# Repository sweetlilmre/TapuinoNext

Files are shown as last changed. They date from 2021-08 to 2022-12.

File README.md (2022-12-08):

# TapuinoNext


## Intro

Welcome to the TapuinoNext alpha.  

Most of the code has been written and tested to a fair extent, but there are bound to be loads of bugs.
Please report bugs as issues against the repo. If you have fixes, please submit these as a pull request.
I could really use some help with documentation in markdown format if you would like to contribute in that way.

## Using the TapuinoNext

Instructions on how to navigate the UI and detail on the TapuinoNext functionality can be found on this page: [TapuinoNext UI](docs/ui/TapuinoNext-UI.md). This is still very much a work in progress.

## Hardware

- "instructions" to build a stripboard prototype are available at [Prototype Build](docs/PrototypeBuild.md)
- schematics and board designs for reference implementations are available in the [Eagle](docs/Eagle) folder.
- the mini board has been produced and tested successfully!
- **NB: the micro board has not**

The BOM for the TapuinoNext is:
- ESP32 Devkit equivalent: e.g. https://www.banggood.com/ESP32-WiFi-+-bluetooth-Development-Board-Ultra-Low-Power-Consumption-Dual-Core-ESP-32-ESP-32S-Similar-ESP8266-Geekcreit-for-Arduino-products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

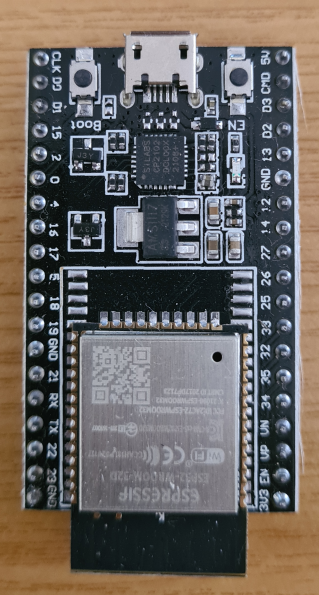
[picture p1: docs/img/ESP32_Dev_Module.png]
ESP32 Dev Module SD Card Adapter


- resistors:
  - (voltage divider)
    - 1k5
    - 3k3
  - 100 Ohm (Recording LED current limiter)
- Rotary encoder KY-040: e.g. https://www.banggood.com/5Pcs-5V-KY-040-Rotary-Encoder-Module-AVR-PIC-p-951151.html

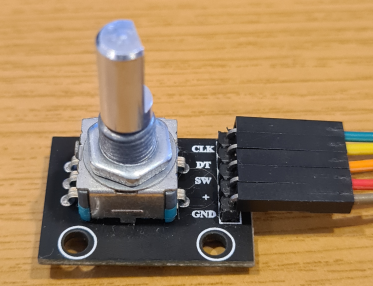
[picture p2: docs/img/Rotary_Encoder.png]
KY-040 Rotary Encoder


- LCD screen: SSD1306 OLED or HD44780 via I2C backpack
- SD Card breakout board / socket, no level shifter! Ones without resistors seem to work better. I used something like this: https://www.mischianti.org/2019/12/15/how-to-use-sd-card-with-esp8266-and-arduino/
This is the one I built:

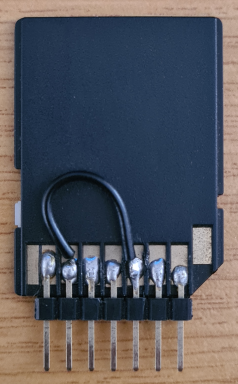
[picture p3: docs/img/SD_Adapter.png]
SD Card Adapter


- Bi-directional level shifter: e.g. https://www.banggood.com/10Pcs-Logic-Level-Converter-Bi-Directional-IIC-4-Way-Level-Conversion-Module-p-1033750.html
  
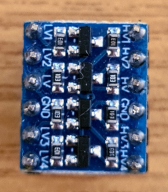
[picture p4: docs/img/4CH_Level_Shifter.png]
4 Channel Level Shifter


- C64 Datasette connector (use one off of a dead datasette or find one of these: https://www.thefuturewas8bit.com/cassette-port-connector-vic20-64-64c-128-128d-pet.html)

Wire this all up according to the schematic and flash the firmware.

## Firmware

If you have already flashed a recent firmware, then firmware releases are available at: https://github.com/sweetlilmre/TapuinoNext/releases

As newer firmware can self update, all you need to do is drop the *update.bin* file onto the root of the SD Card and select the firmware update option from the options menu.

For a first time build:

There is now an alternative to building the code and flashing.
- Download the latest `update.factory.bin` from the [TapuinoNext Releases Page ](https://github.com/sweetlilmre/TapuinoNext/releases)
- Using Google Chrome, go to the [Adafruit ESP Tool](https://adafruit.github.io/Adafruit_WebSerial_ESPTool/) page.
- Connect your ESP32 to your machine and make sure the drivers are installed
- Click "Connect" on the Adafruit page and select the COM port of your ESP32
- If the connect succeeds, you should see several `Choose a file...` buttons
- Click the first one, navigate to and select the `update.factory.bin` file you downloaded
- Click `Program`
- A progress bar will appear, once this is complete you should be good to go

Probably the easiest way to handle this at the moment is to:
- install VS Code
- install Platformio on top of that
- install the Espressif 32 platform or start a new project and choose "Espressif ESP32 Dev Module" as the board, with "Arduino" as the framework
- clone the TapuinoNext repository
- you will need to create a ***config-user.h*** file in the include directory. This is currently used to specify which of the 2 supported displays you have and what the correct I2C address for the display is. A sample ***config-user.h.example*** has beem provided
- point VS code to the directory you cloned the repo into and upload to the board (I'm assuming that you know how to do all of this)

## TODO / Roadmap

See [TODO](TODO.md)

## Attribution

See [Attribution](docs/Attribution.md)

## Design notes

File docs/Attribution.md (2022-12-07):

# Attibution for documentation and hardware designs:

## Fritzing
### TapuinoNext layout:

- Original design: Attila Gabriel  
- Fixes and edits by sweetlilmre

### Components:

ESP32-38PinWide-Component.fzpz:  
- https://forum.fritzing.org/t/fritzing-part-of-an-esp32/5355/4
  - https://forum.fritzing.org/uploads/default/original/2X/8/8d99adbb2e8f966178bdb46f5cffa7bd72ce2c2a.fzpz

KY-040_AZ_Rotary_encoder_v0.fzpz:  
- https://forum.fritzing.org/t/ky-040-rotary-encoder-breakout-board-part/11073
  - https://forum.fritzing.org/uploads/short-url/bN5n4wTJwT4cgNHyY3Omdc8aznC.fzpz

SD_Card_Module.fzp:  
- https://github.com/robertoostenveld/fritzing/blob/master/SD%20Card%20Module.fzpz
  - https://github.com/robertoostenveld/fritzing/raw/master/SD%20Card%20Module.fzpz

## Eagle parts
2 Pin Header part  
For some inexplicable reason the built in Eagle libraries do not have a 2 pin male header (starts at 3 pin). This part is a rework of the 3 pin part.  
<br>
ESP32 Devkit part  
Nothing on the internet that I could find had either the correct pin out or size for the dev kit board. I have created a part heavily inspired by the following:
- https://hackaday.io/project/46280-muffsy-stereo-relay-input-selector/log/87314-esp32s-devkit-eagle-library
  - https://cdn.hackaday.io/files/462801980043520/ESP32-DEVKITC.lbr
## Others:
PNG Images, stripboard design, schematics, board and libraries
- sweetlilmre

## Factory bin image generation script:
https://raw.githubusercontent.com/letscontrolit/ESPEasy/3678488f6a67ac9b899fab3d0ccd176c4437b1b4/tools/pio/post_esp32.py

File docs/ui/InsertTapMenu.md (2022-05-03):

# TapuinoNext UI

## Insert Tap

Once you have selected this menu option you will be taken to the file browser. Navigate through the files to select a TAP file you wish to load and then use the **Button** action to select that file.

Directories can be selected in the same manner, use the previous directory ".." to go up one level.

TAP files with names longer than the LCD display width will scroll after a short pause. The scroll rate can be changed in the [Options Menu](/docs/ui/OptionsMenu.md).

Once you have selected a TAP file, the file will be verified and on success you will be taken to the [Play Menu](PlayMenu.md).

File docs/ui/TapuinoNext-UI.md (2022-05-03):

# TapuinoNext UI

## Navigation

The rotary encoder is used to navigate through the various menus, options and functions of the firmware.

| Encoder action | Description | UI Result |
| --- | --- | --- |
| Left | Turn encoder anti-clockwise | Previous menu / item |
| Right | Turn encoder clockwise | Next menu / item |
| Button | Press the encoder button | Select |
| ButtonHold | Press and hold the encoder button | Back / cancel |

The **Button** and **ButtonHold** actions have context specific functionality that will be described in the corresponding help sections.

### Menu Navigation

- Use the encoder to scroll through the menus at the current level.
- Use **Button** to select a sub-menu / action
- Use **ButtonHold** to return to the previous menu

## Main Menu

Once the TapuinoNext has booted successfully (displayed the startup screen with version number and initialised) the Main Menu will display, defaulting to the first option: Insert Tap

Scroll through these options using the encoder and then use the **Button** to select one. The 3 main menu options are:

- [Insert Tap](InsertTapMenu.md)
- [Record Tap](RecordTapMenu.md)
- [Options](OptionsMenu.md)

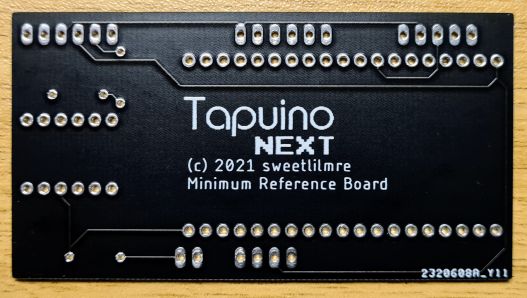
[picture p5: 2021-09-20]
docs/img/TapuinoNext-Mini.jpg

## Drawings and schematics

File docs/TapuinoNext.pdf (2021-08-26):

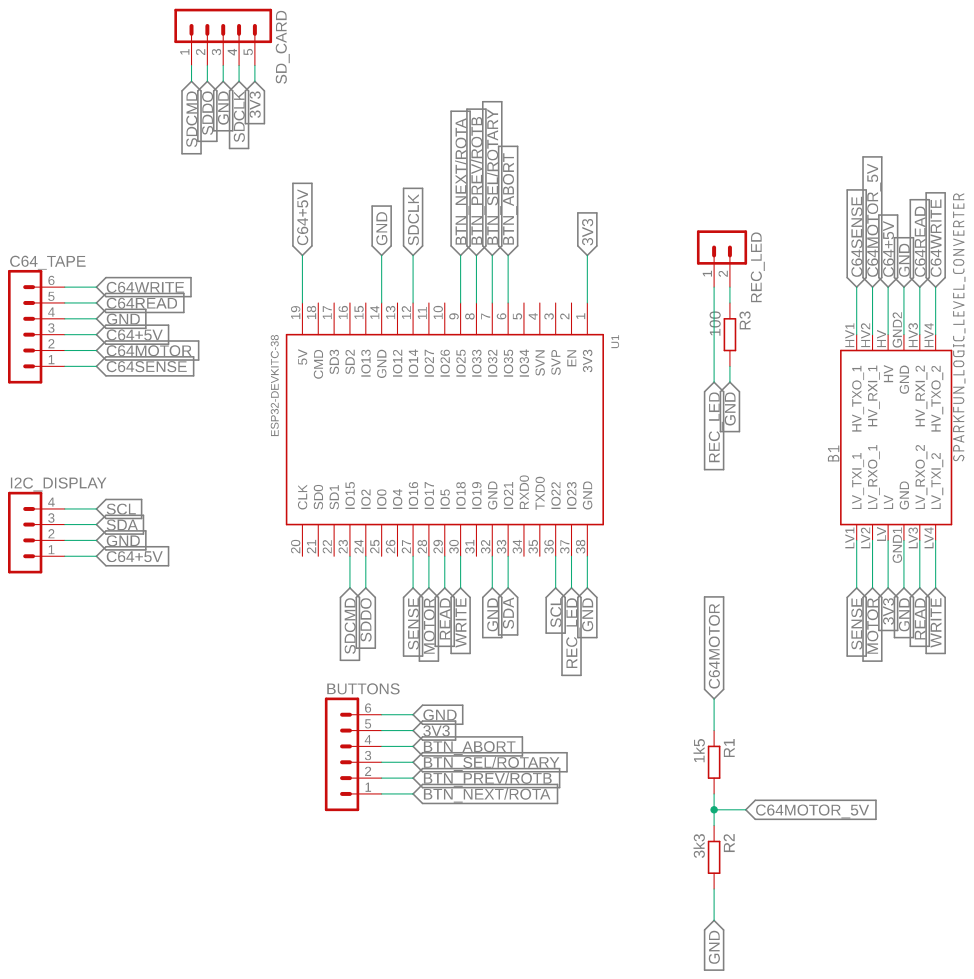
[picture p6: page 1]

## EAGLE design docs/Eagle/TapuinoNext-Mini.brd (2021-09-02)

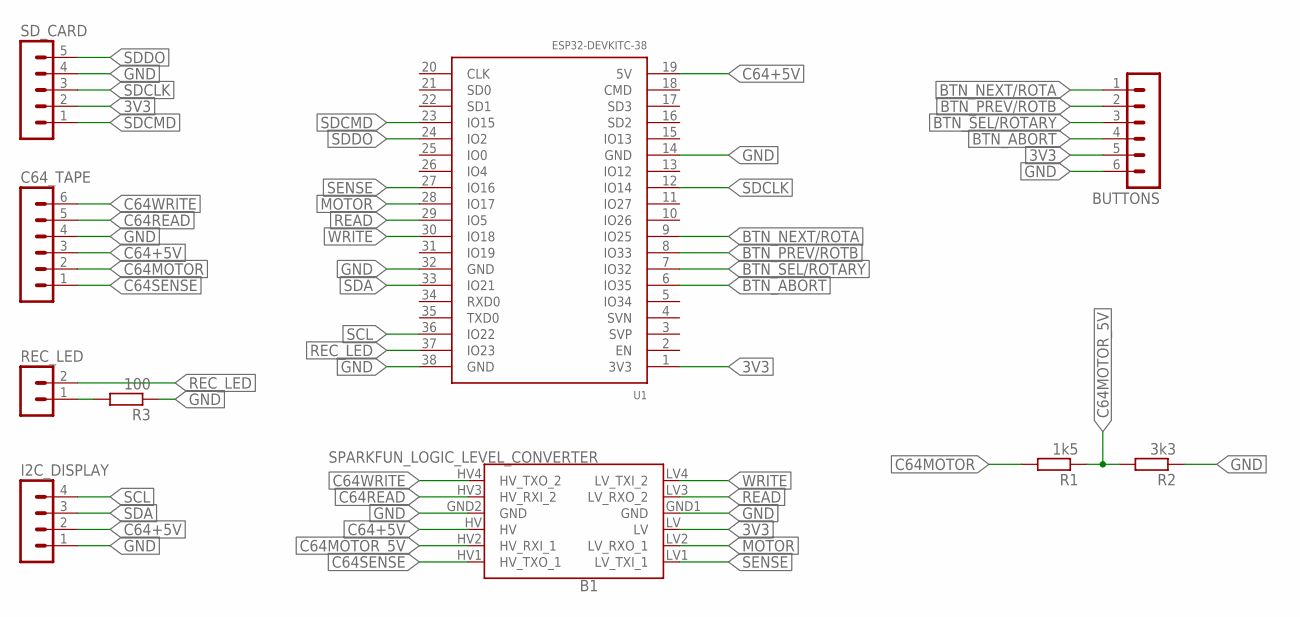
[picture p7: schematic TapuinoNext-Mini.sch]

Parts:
B1: SPARKFUN_LOGIC_LEVEL_CONVERTER
BUTTONS: MA06-1
C64_TAPE: MA06-1
I2C_DISPLAY: MA04-1
R1: 1k5; 0207/10
R2: 3k3; 0207/10
R3: 100; 0207/10
REC_LED: MA02-1
SD_CARD: MA05-1
U1: ESP32-DEVKITC-38

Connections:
3V3: B1.LV, BUTTONS.5, SD_CARD.2, U1.1 (3V3)
BTN_ABORT: BUTTONS.4, U1.6 (IO35)
BTN_NEXT/ROTA: BUTTONS.1, U1.9 (IO25)
BTN_PREV/ROTB: BUTTONS.2, U1.8 (IO33)
BTN_SEL/ROTARY: BUTTONS.3, U1.7 (IO32)
C64+5V: B1.HV, C64_TAPE.3, I2C_DISPLAY.2, U1.19 (5V)
C64MOTOR: C64_TAPE.2, R1.2
C64MOTOR_5V: B1.HV2 (HV_RXI_1), R1.1, R2.2
C64READ: B1.HV3 (HV_RXI_2), C64_TAPE.5
C64SENSE: B1.HV1 (HV_TXO_1), C64_TAPE.1
C64WRITE: B1.HV4 (HV_TXO_2), C64_TAPE.6
GND: B1.GND1 (GND), B1.GND2 (GND), BUTTONS.6, C64_TAPE.4, I2C_DISPLAY.1, R2.1, R3.1, SD_CARD.4, U1.14 (GND), U1.32 (GND), U1.38 (GND)
MOTOR: B1.LV2 (LV_RXO_1), U1.28 (IO17)
unnamed: R3.2, REC_LED.1
READ: B1.LV3 (LV_RXO_2), U1.29 (IO5)
REC_LED: REC_LED.2, U1.37 (IO23)
SCL: I2C_DISPLAY.4, U1.36 (IO22)
SDA: I2C_DISPLAY.3, U1.33 (IO21)
SDCLK: SD_CARD.3, U1.12 (IO14)
SDCMD: SD_CARD.1, U1.23 (IO15)
SDDO: SD_CARD.5, U1.24 (IO2)
SENSE: B1.LV1 (LV_TXI_1), U1.27 (IO16)
WRITE: B1.LV4 (LV_TXI_2), U1.30 (IO18)

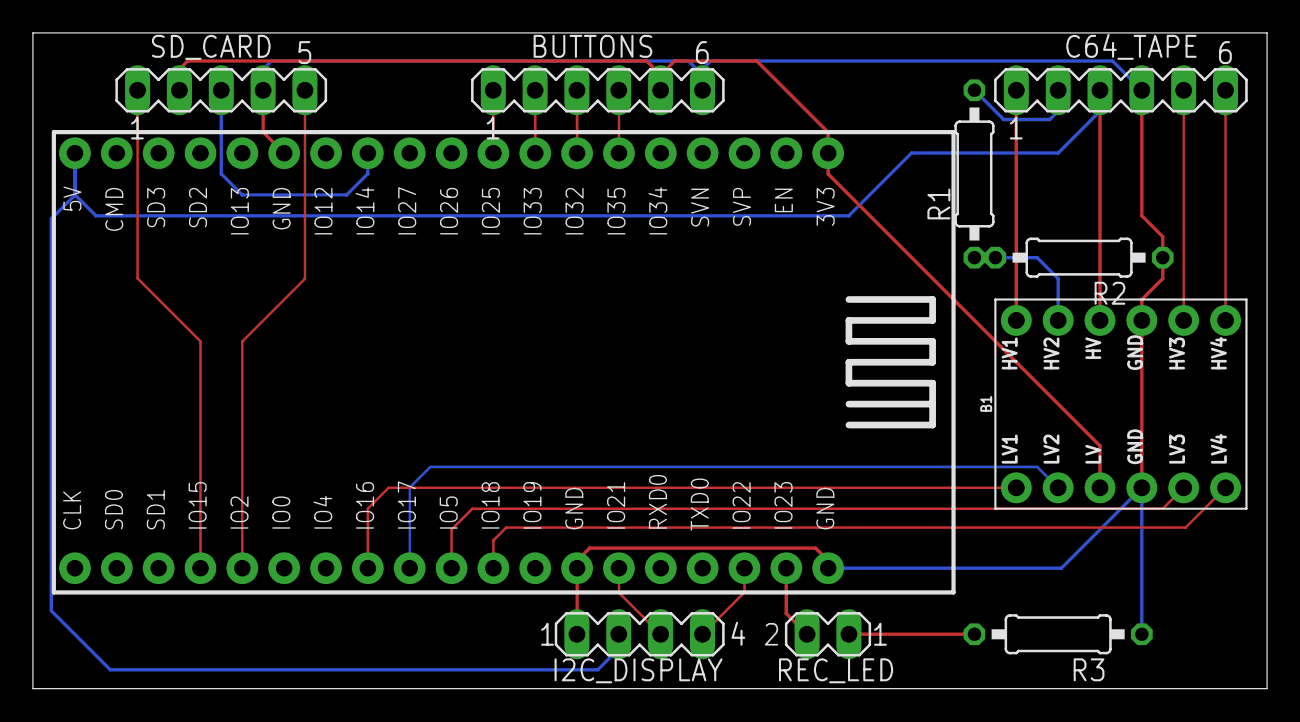
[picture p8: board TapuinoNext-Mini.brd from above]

Board: 2 copper layers, 74.9 x 39.8 mm, 10 parts (0 on the bottom side), 23 nets.

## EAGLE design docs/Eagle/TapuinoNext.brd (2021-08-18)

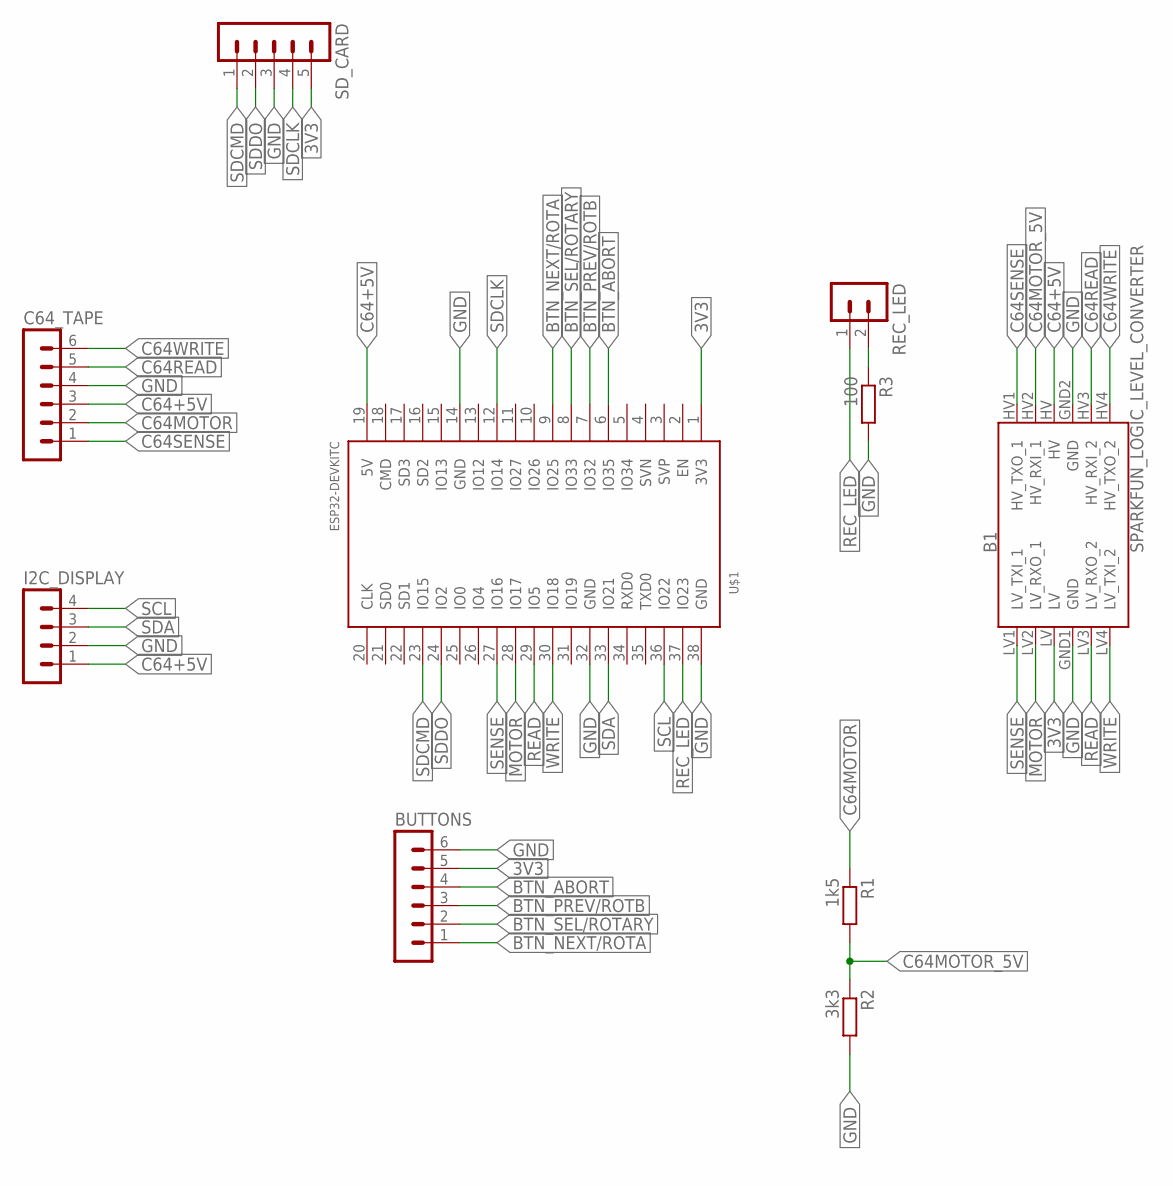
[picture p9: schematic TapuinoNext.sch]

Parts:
B1: SPARKFUN_LOGIC_LEVEL_CONVERTER
BUTTONS: MA06-1
C64_TAPE: MA06-1
I2C_DISPLAY: MA04-1
R1: 1k5; 0204/7
R2: 3k3; 0204/7
R3: 100; 0204/7
REC_LED: MA02-1
SD_CARD: MA05-1
U$1: ESP32DEVKITC; ESP32-DEVKITC

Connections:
3V3: B1.LV, BUTTONS.5, SD_CARD.5, U$1.1 (3V3)
BTN_ABORT: BUTTONS.4, U$1.6 (IO35)
BTN_NEXT/ROTA: BUTTONS.1, U$1.9 (IO25)
BTN_PREV/ROTB: BUTTONS.3, U$1.7 (IO32)
BTN_SEL/ROTARY: BUTTONS.2, U$1.8 (IO33)
C64+5V: B1.HV, C64_TAPE.3, I2C_DISPLAY.1, U$1.19 (5V)
C64MOTOR: C64_TAPE.2, R1.1
C64MOTOR_5V: B1.HV2 (HV_RXI_1), R1.2, R2.1
C64READ: B1.HV3 (HV_RXI_2), C64_TAPE.5
C64SENSE: B1.HV1 (HV_TXO_1), C64_TAPE.1
C64WRITE: B1.HV4 (HV_TXO_2), C64_TAPE.6
GND: B1.GND1 (GND), B1.GND2 (GND), BUTTONS.6, C64_TAPE.4, I2C_DISPLAY.2, R2.2, R3.2, SD_CARD.3, U$1.14 (GND), U$1.32 (GND), U$1.38 (GND)
MOTOR: B1.LV2 (LV_RXO_1), U$1.28 (IO17)
unnamed: R3.1, REC_LED.2
READ: B1.LV3 (LV_RXO_2), U$1.29 (IO5)
REC_LED: REC_LED.1, U$1.37 (IO23)
SCL: I2C_DISPLAY.4, U$1.36 (IO22)
SDA: I2C_DISPLAY.3, U$1.33 (IO21)
SDCLK: SD_CARD.4, U$1.12 (IO14)
SDCMD: SD_CARD.1, U$1.23 (IO15)
SDDO: SD_CARD.2, U$1.24 (IO2)
SENSE: B1.LV1 (LV_TXI_1), U$1.27 (IO16)
WRITE: B1.LV4 (LV_TXI_2), U$1.30 (IO18)

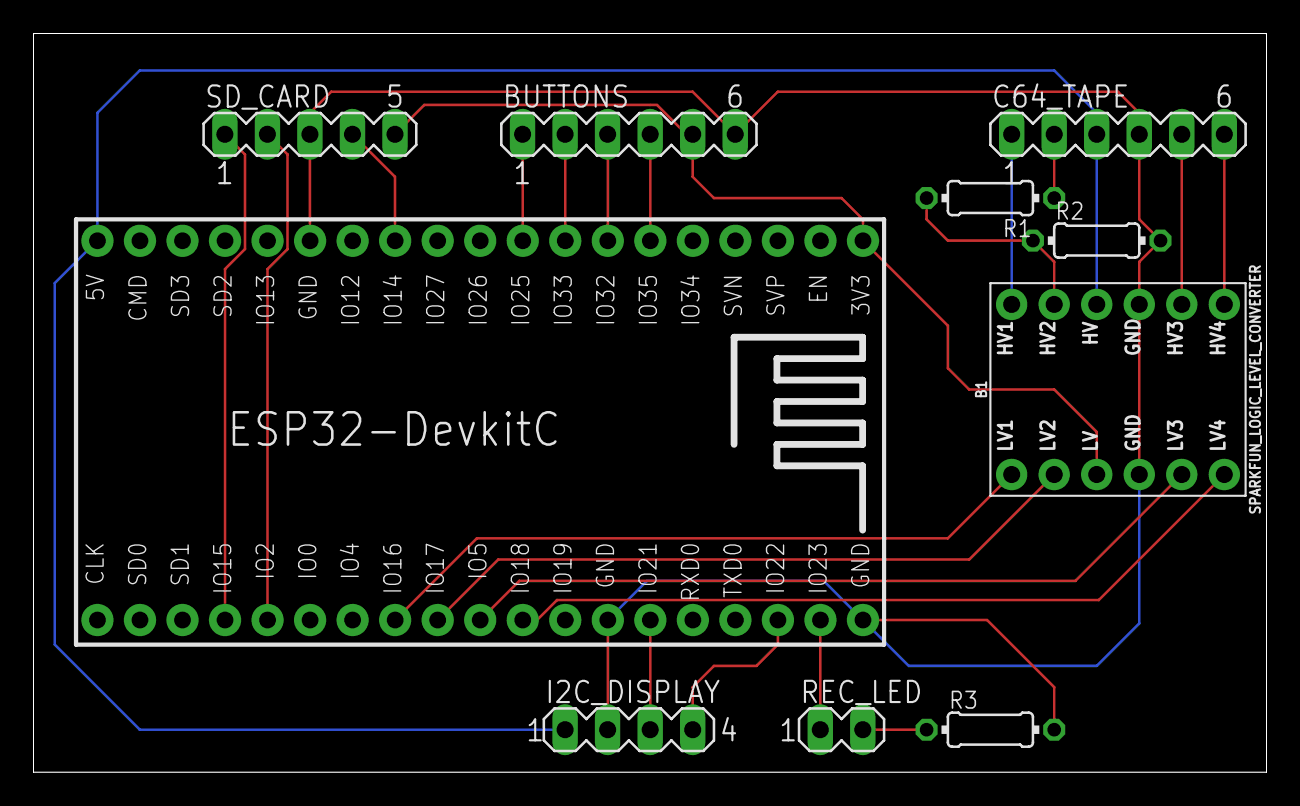
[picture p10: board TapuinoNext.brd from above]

Board: 2 copper layers, 73.6 x 44.1 mm, 10 parts (0 on the bottom side), 23 nets.

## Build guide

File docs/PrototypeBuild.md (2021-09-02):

# The first working prototype
This was built on stripboard. The design is in the LochMaster folder (you can download the LochMaster demo for free IIRC).

## Stripboard Legend
Please pay careful attention to the legend, specifically the cut track marks.  
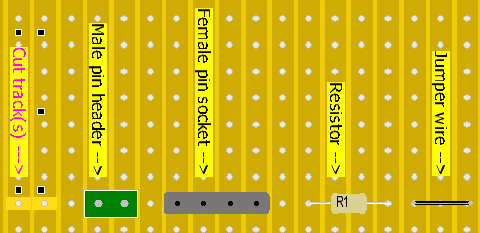
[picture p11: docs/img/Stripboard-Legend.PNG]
Stripboard Legend


## Stripboard Top View
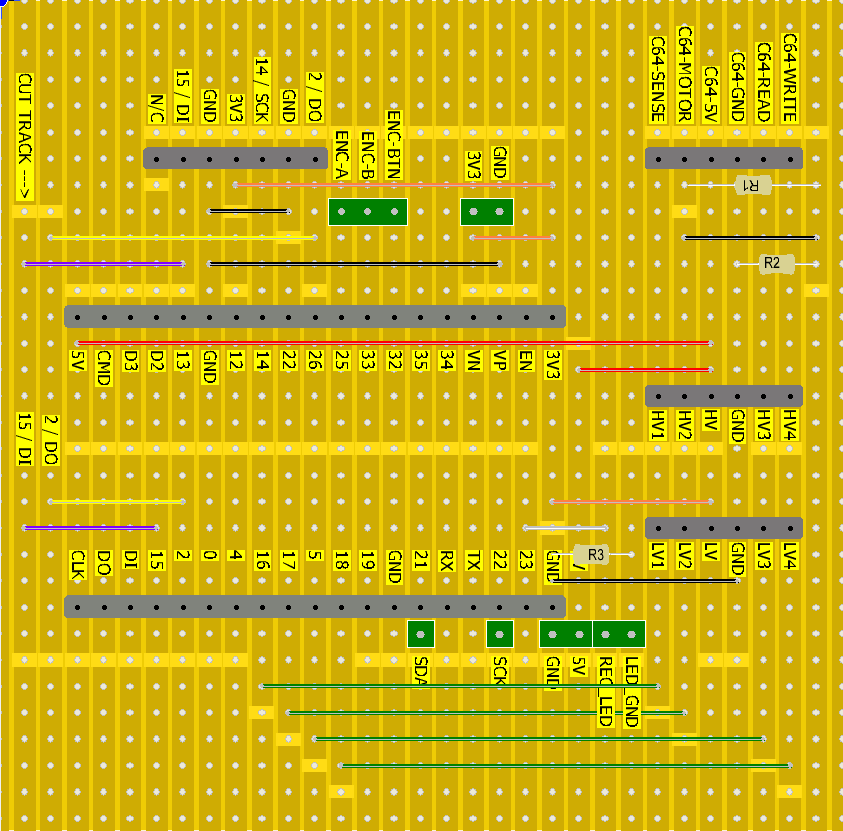
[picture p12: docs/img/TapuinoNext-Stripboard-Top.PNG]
Stripboard Top View


## Stripboard xray view
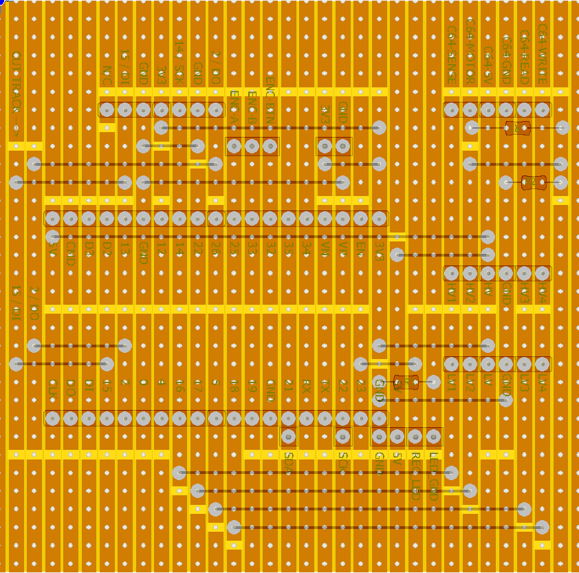
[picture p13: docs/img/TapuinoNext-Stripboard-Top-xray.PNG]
Stripboard xray View


## Stripboard used area view
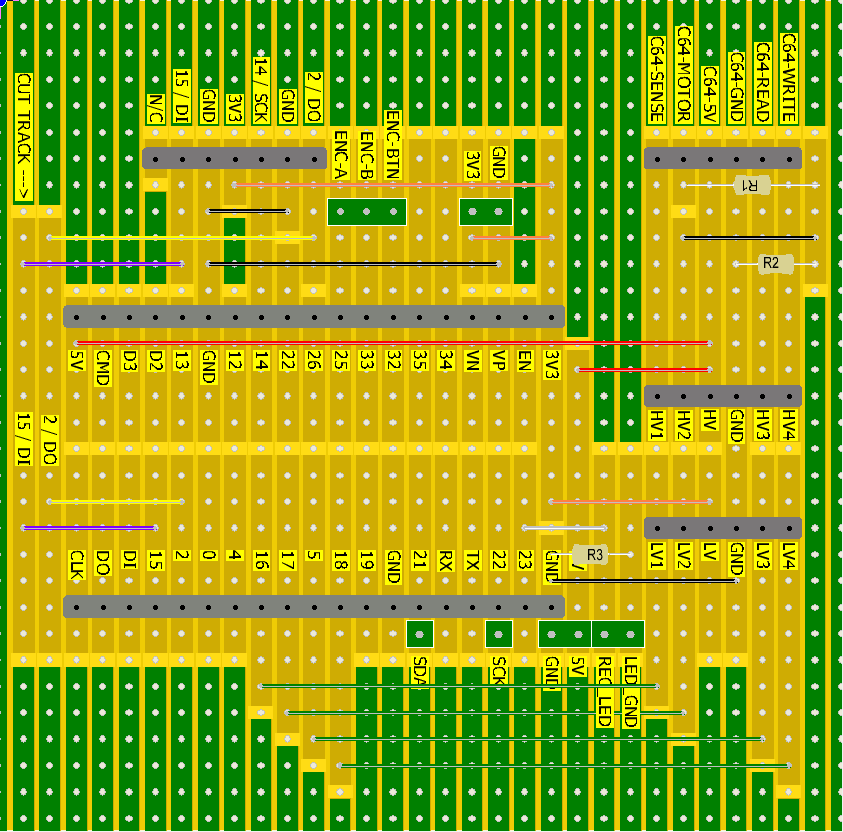
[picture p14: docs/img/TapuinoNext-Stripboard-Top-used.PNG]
Stripboard Used Area View


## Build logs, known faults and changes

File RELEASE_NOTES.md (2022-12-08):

*****************************************
** TapuinoNext Release Notes           **
** sweetlilmre <sweetlilmre@gmail.com> **
*****************************************

## v0.0.3-alpha+267 - 08 December 2022

### Feature
  - Added `update.factory.bin` to the build and release artifacts
  - Updated documentation to show how to flash the firmware from a browser, using `update.factory.bin`
  - Internal changes to support the above

### Fix
  - Fixed printing of the TapuinoNext version to the serial port 

## v0.0.3-alpha+240 - 22 June 2022

### Feature
  - Added file filtering change to exclude files starting with . (remove Mac specific folders) (predecker)
  - Added TODO.md to keep some kind of roadmap going

### Fix
  - Previous directory fix (predecker)
  - Changed start recording message to be clearer

### Internal
  - Changed changelog format for automatic release note generation
  - Added 'v' to version, should have been there from the begining
    - fixed auto_version.py to support this
  - Moved large buffer handling to FlipBuffer
    - Cleaned up implementation in TapLoader and TapRecorder
  - Added raw TapeCart implementation code

## v0.0.2-alpha+237 - 04 June 2022
  - Fixed various compatibility issues with framework-arduinoespressif32 > 2.0.1
    - the platform is pinned to version 4.0.1 (and hence framework 2.0.1) waiting for timer fixes to get into the next framework release and platform update (4.0.5 and 2.0.4?)
    - timer functionality was changed from a re-triggered one-shot to a repeat timer (retriggered one-shot does not work in the context of the move to IDF4.4 from framework 2.0.2)
    - input initialisation in the constructor of ESP32InputHandler.cpp also broke (shouldn't have done this in the first place)

  - Other minor improvments
    - changed the text for the firmware update menu to make it less confusing
    - added the spinner UI into the update progress display
    - changed the name of the firmware release to "update.bin" for ease of use

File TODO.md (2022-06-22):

**TODO / Roadmap**

- Implement ini file for LCD selection, write default if it does not exist
  - Defaults will be
    - `#define I2C_DISP_ADDR 0x27`
    - `#define I2C_DISP_TYPE I2C_DISP_TYPE_HD44780`
- Finish TapeCart implementation
  - Run basic test with a buffer and built in PRG to test timing and handshake with C64 loader
    - Changed approach to use a file, still to test, requires changes below
    - ~~Implement basic loader pre-code check for $0801 load address PRGs~~
    - ~~Might need to change the loader to wait for the sense line signal (currently commented out), but would be useful to allow setup time for files / buffers~~
      - Looks like the wait on SENSE will take care of this
  - ~~Move buffer handling to a separate class (save on heap space, share buffer and have single allocation)~~
  - Add PRG as allowable extension to LoadSelector
    - Differentiate behaviour depending on TAP / PRG load
- C16 TAP (1/2 wave) playback
  - Fix cycle counting
  - Implement 1/2 wave recording
- Implement other machine type timings (PET etc) and check values against Vice
- Add file / dir filter to remove hidden directories (MacOS / Win / etc?)
  - Waiting on PR from contributor

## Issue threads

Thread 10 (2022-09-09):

Question regarding sense signal & record LED

Pentasis, 2022-09-09:
Hi, sorry for asking this here.
I am currently building (well, designing for now) a tapuino into an old 1530 case. I want to keep it as original as possible, so I put the display and the sd-card into the tape-lid and reuse the original buttons (which is a bit of a challenge).

I also want the counter to actually work (just because), so I intend to put a small motor in there. I'm still in the design-stage so don't have the actual parts yet. I want it to turn only when reading/writing. Is the sense-signal suitable for that? Is it continuously on while reading/writing? Also, is it 5V?

Also, I assume the record_LED only works when recording (writing) not reading, right? As a feature request, could a read_LED be implemented? (In the end I will probably use a multi-colour-led as a replacement for the original one and have it switch colours depending on power/read/write)

sweetlilmre, 2022-09-12:
Hi there,

SENSE is activated on the datasette by pressing PLAY (or record and play). IIRC it will be on for the duration, although there are cases where  SENSE will be active but the motor has stopped (game has finished loading). As I have the correct formula for calculating the counter, I would suggest replacing the analogue counter with a digital one and we could look at some digital interface to communicate the value (I2C perhaps?). A small oled screen or very small I2C 3-digit 7 segment display could be awesome for this.

As for LEDs, there are plenty of pins available so I could add read and/or write LEDS, something I had meant to do.

How are you building the TapuinoNext? On breadboard or using the reference PCB? I might need to change some pin assignments if I'm going to add further LEDs or a counter interface to the code and will then need to update the schematic if you are using the PCB.

sweetlilmre, 2022-12-17:
Closing this issue as no response from OP.

Closed 2022-12-17.

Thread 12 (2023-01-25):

Tapuino + touch GUI

dejwk, 2023-01-25:
Hi Peter,

I see that you are porting Tapuino to ESP32. It's very cool, since ESP32 is so much more capable!

Anyway - my name is Dawid, and I wrote a GUI library for the ESP32. As a proof-of-concept, I wrote a GUI app for Tapuino. I made a short YouTube demo video, here:

https://www.youtube.com/watch?v=Aub32NOzwNY

In addition to the GUI part, it's probably worth noting that it supports loading directly from ZIP files, and it can handle SD cards with thousands of TAPs.

If you were interested, I'd be happy to contribute that app to be part of your project.

The GUI lib is still somewhat experimental (e.g. no documentation); with that caveat, you can find it here: https://github.com/dejwk/roo_windows. I didn't upload the app itself to Github just yet.

The TFT I used isn't great (it has a resistive touch, and it needs a stylus), but it's cheap and it has a built-in SD card reader. Hence, for my prototype build, I only needed two active components (ESP32 + display), and just a few passive elements. There are better TFTs, though. I have good experience with Waveshare ILI9486-based; I also ordered something with capacitive touch to experiment with.

sweetlilmre, 2023-02-21:
Hi Dawid,
I was sure I had responded to you, but must have forgot to send the response.

This looks like a really nice GUI and I'd be keen to support something like this.
What I do need to do first is some abstraction work on the current UI handling so that multiple UIs could be integrated depending on hardware choice. I'd be interested to see how you wove your UI into the current project.

Apologies for getting back to you so late.

dejwk, 2023-03-01:
Thanks Peter!

I dumped the PoC here if you'd like to take a look: https://github.com/dejwk/tapuino2

(It depends on a number of libs from https://github.com/dejwk; I didn't yet do anything to make it easy to build, so if you'd like to build it, you'll need to manually fetch roo_time, roo_scheduler, roo_display, roo_windows, roo_material_icons, and roo_dashboard - by cloning them into the lib/ subdirectory. It also needs  unzipLIB to handle ZIP files.)

It is a proof-of-concept; it doesn't support seek, updates, and writes - but all possible to add. I also intended to implement a search-as-you-type interface; the index is prepared for that but the UI isn't implemented yet.

The most recent implementation uses a MakerFabs display (based on ili9488), which I am very pleased with - it has very good resolution (480x320), an excellent capacitive touch panel, and ESP32 and SD card reader on board - so really the only bits needed to make a functional Tapuino out of that single component are a few passive elements (voltage dividers and a capacitor on the power line). That said, the underlying UI library supports a number of TFT display drivers so there's some flexibility built-in.

Re: how to refactor the project so that it can work with different UX interfaces: I think the way to go is to make the core event-driven. That is, the 'main loop' needs to be outside of the core, and controlled by the specific UI implementation. Then, you can have completely different UX on top of the same core. (By core, I mean the code that handles the filesystem, TAP playback, etc.)

This is how my PoC is currently implemented, so you can see what I mean in the code. Basically, the UX *is* the app, and it calls to the core when needed, e.g. when something is pressed, as well as periodically during playback (to replenish the read buffer).

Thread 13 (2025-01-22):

Unfortunately it will never really work...

0wwafa, 2025-01-22:
I am doing a similar project and I stumbled into an esp32 bug.

You can read about it here: https://github.com/espressif/arduino-esp32/issues/10894

In short:

create a tap of 2 minutes with a single frequency.. let's say a tap v1 made of all "99".

put it on the u2 plus and send it to the "tape".

record the pulses with the esp32.

you will miss one pulse every 17.8 seconds.

please help me debug this and let's inform expressif of this.

perhaps it's some overflow somewhere in Free RTOS.

0wwafa, 2025-01-22:
this makes me very angry because other than that, the ESP32 can get every single pulse with PERFECT timing.
damn!
useless device thanks to a horrible "RTOS". :(
I tried disabling everything.. wifi, watchdogs, bluetooth... no change.

Any idea?

dashxdr, 2025-01-27:
> this makes me very angry because other than that, the ESP32 can get every single pulse with PERFECT timing. damn! useless device thanks to a horrible "RTOS". :( I tried disabling everything.. wifi, watchdogs, bluetooth... no change.
>
> Any idea?

Upgrade to a more recent esp/idf

0wwafa, 2025-01-28:
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

I have the same as you are using.

sweetlilmre, 2025-01-30:
Someone mentioned using the RMT peripheral to accurately count pulses or MCPWM (which I no nothing about).
https://esp32.com/viewtopic.php?t=13128
https://esp32.com/viewtopic.php?t=1772

uzi18, 2025-01-30:
@0wwafa please point me to afected function

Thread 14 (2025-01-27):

How is this project built?

dashxdr, 2025-01-27:
I have no familiarity with the platform this is built under, what build system... No Makefiles, no sdkconfig.defaults, no CMakeLists.txt, no obvious IDE files...

Any leg up of any kind would be most welcome

sweetlilmre, 2025-01-30:
`platformio.ini` is your clue :)
Load the project into VSCode with an installed PlatformIO extension and the espressif ESP-IDF framework installed.
Then perform a usual PlatformIO build.

Closed 2025-01-30.

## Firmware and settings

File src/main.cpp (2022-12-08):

#ifdef ESP32

#include <iostream>
#include <string>
#include <vector>

#include "FS.h"
#include "Lang.h"
#include "LoadSelector.h"
#include "Menu.h"
#include "Options.h"
#include "RecordSelector.h"
#include "SD_MMC.h"
#include "config.h"
#include "OptionEventHandler.h"

using namespace std;
using namespace TapuinoNext;

#include "ESP32FileLoader.h"
#include "ESP32InputHandler.h"
#include "ESP32TapLoader.h"
#include "ESP32TapRecorder.h"
#include "FS.h"
#include "LCD_HD44780.h"
#include "OLED_1306.h"
#include "Updater.h"

#include "Version.h"

OptionEventHandler optionEventHander;

ESP32FileLoader theFileLoader;

#if I2C_DISP_TYPE == I2C_DISP_HD44780
LCD_HD44780 theLCD(&optionEventHander);
#else
OLED_1306 theLCD(&optionEventHander);
#endif

ESP32InputHandler theInputHandler(&optionEventHander);
LCDUtils lcdUtils(&theLCD);

void testInputHander()
{
    while (true)
    {
        switch (theInputHandler.GetInput())
        {
            case InputResponse::Next:
                Serial.println("next");
                break;
            case InputResponse::Prev:
                Serial.println("prev");
                break;
            case InputResponse::Select:
                Serial.println("Select");
                break;
            case InputResponse::Abort:
                Serial.println("Abort");
                break;
            default:
                break;
        }
    }
}

void testPins()
{
    pinMode(C64_SENSE_PIN, OUTPUT);
    digitalWrite(C64_SENSE_PIN, LOW);

    pinMode(C64_MOTOR_PIN, INPUT_PULLDOWN);

    pinMode(C64_READ_PIN, OUTPUT);
    digitalWrite(C64_READ_PIN, LOW);

    pinMode(C64_WRITE_PIN, INPUT_PULLDOWN);

    char buf[51];
    memset(buf, 0, 51);
    while (true)
    {
        int w = digitalRead(C64_WRITE_PIN);
        int m = digitalRead(C64_MOTOR_PIN);
        int s = digitalRead(C64_SENSE_PIN);
        int r = digitalRead(C64_READ_PIN);

        snprintf(buf, 50, "W-%c M-%c S-%c R-%c", w ? 'H' : 'L', m ? 'H' : 'L', s ? 'H' : 'L', r ? 'H' : 'L');
        lcdUtils.Title(buf);

        delay(500);
    }
}

void testEncoderPins()
{
    Serial.println("testEncoderPins");
    pinMode(ROTARY_ENCODER_A_PIN, INPUT_PULLUP);
    pinMode(ROTARY_ENCODER_B_PIN, INPUT_PULLUP);

    char buf[50];
    int oldA = digitalRead(ROTARY_ENCODER_A_PIN);
    int oldB = digitalRead(ROTARY_ENCODER_B_PIN);
    strcpy(buf, "00 AB State\n");
    buf[0] = oldA ? '1' : '0';
    buf[1] = oldB ? '1' : '0';
    Serial.print(buf);

    Button encoderButton;
    encoderButton.Init(ROTARY_ENCODER_BUTTON_PIN);

    while (true)
    {
        int a = digitalRead(ROTARY_ENCODER_A_PIN);
        int b = digitalRead(ROTARY_ENCODER_B_PIN);
        if (a != oldA || b != oldB)
        {
            oldA = a;
            oldB = b;

            buf[0] = oldA ? '1' : '0';
            buf[1] = oldB ? '1' : '0';
            Serial.print(buf);
        }
        if (encoderButton.GetState() == ButtonState::CLICKED)
        {
            Serial.println("--------------------------------");
        }
    }
}

bool initTapuino()
{
    Serial.begin(115200);
    Serial.println(S_INIT);
    theLCD.Init(I2C_DISP_ADDR);

    lcdUtils.Title("TapuinoNext");
    Serial.println("TapuinoNext");

    //testEncoderPins();
    theInputHandler.Init();

    char version[I2C_DISP_COLS + 1];
    memset(version, 0, I2C_DISP_COLS + 1);
    snprintf(version, I2C_DISP_COLS + 1, "%s", FW_VERSION);
    lcdUtils.Status(version);
    Serial.println(version);
    delay(2000);

    lcdUtils.Status(S_INIT);
    Serial.println("Starting SD init");

    if (!theFileLoader.Init())
    {
        Serial.println(S_INIT_FAILED);
        lcdUtils.Status(S_INIT_FAILED);
        return false;
    }
    Serial.println(S_INIT_OK);
    lcdUtils.Status(S_INIT_OK);
    delay(1000);
    return (true);
}

MenuEntry mainMenuEntries[] = {
    {MenuEntryType::IndexEntry, S_INSERT_TAP, NULL},
    {MenuEntryType::IndexEntry, S_RECORD_TAP, NULL},
    {MenuEntryType::IndexEntry, S_OPTIONS, NULL},
};

TheMenu mainMenu = {S_MAIN_MENU, (MenuEntry*) mainMenuEntries, 3, 0, NULL};

void setup()
{
    if (!initTapuino())
        return;

    MenuHandler menu(&lcdUtils, &theInputHandler);
    Updater updater(&lcdUtils, &theInputHandler, &theFileLoader);

    Options options(&theFileLoader, &optionEventHander, &menu, &updater);

    FlipBuffer flipBuffer(4096);
    ErrorCodes ret = flipBuffer.Init();
    if (ret != ErrorCodes::OK)
    {
        lcdUtils.Error(S_OUT_OF_MEMORY, ret);
        while (1) {}
    }

    UtilityCollection utilityCollection(&lcdUtils, &theInputHandler, &theFileLoader, &options, &flipBuffer);
    LoadSelector lsel(&utilityCollection);
    RecordSelector rsel(&utilityCollection);
    options.LoadOptions();

    while (true)
    {
        int index = menu.Display(&mainMenu);
        switch (index)
        {
            case 0:
            {
                lsel.OnAction();
                break;
            }
            case 1:
            {
                rsel.OnAction();
                break;
            }
            case 2:
            {
                options.OnAction();
                break;
            }
        }
    }
}

void loop()
{
}

#endif

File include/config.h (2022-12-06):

#pragma once
#define ROTARY_ENCODER_A_PIN 25
#define ROTARY_ENCODER_B_PIN 33
#define ROTARY_ENCODER_BUTTON_PIN 32
#define C64_SENSE_PIN 16
#define C64_MOTOR_PIN 17
#define C64_READ_PIN 5
#define C64_WRITE_PIN 18

#define I2C_DISP_TYPE_HD44780 0
#define I2C_DISP_TYPE_SSD1306 1

#define LCD_SSD1306_128x64

#include "config-user.h"

#ifndef I2C_DISP_ADDR
#error Please define "I2C_DISP_ADDR" in config-user.h. Create this file if it does not exist!
#endif

#ifndef I2C_DISP_TYPE
#error Please define "I2C_DISP_TYPE" as "I2C_DISP_TYPE_HD44780" or "I2C_DISP_TYPE_SSD1306" in config-user.h. Create this file if it does not exist!
#endif

#ifndef I2C_DISP_HD44780_SIZE 
    #define I2C_DISP_ROWS 2
    #define I2C_DISP_COLS 16
#elif I2C_DISP_HD44780_SIZE == 2004
    #define I2C_DISP_ROWS 4
    #define I2C_DISP_COLS 20
#else
    #define I2C_DISP_ROWS 2
    #define I2C_DISP_COLS 16
#endif

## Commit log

2021-08-02 - added some serial messages for circuit debugging. - begining rotoarty rework
    [ESP32InputHandler.cpp, main.cpp]
2021-08-18 Added loads of documentation
    [TapuinoNext.brd, TapuinoNext.fzz, TapuinoNext.sch]
2021-08-18 Added reference board silkscreen (c) text
    [TapuinoNext.brd]
2021-08-18 add rec led and tidied up the board / schematic
    [TapuinoNext.brd, TapuinoNext.sch]
2021-08-18 Added 2 pin part for record LED
    [TapuinoNext.brd]
2021-08-25 fixed definition for OLED1306 added the correct part for tthe ESP32 Devkit added a micro board for system builders (trying to keep this to the smallest footprint possible for custom builds) fixed the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
    [TapuinoNext-Micro.brd, TapuinoNext-Micro.sch, TapuinoNext-Mini.brd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]
2021-08-25 Fixed wiring for rotarty in Fritzing sketch
    [TapuinoNext.fzz]
2021-08-26 Changed rotary wiring back to original to match stripboard
    [TapuinoNext-Micro.brd, TapuinoNext-Micro.sch, TapuinoNext-Mini.brd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]
2021-08-26 updated pdf of schematic to reflect changes
2021-08-26 update stripboard files (added led) updated fritzing files (added led) added legend for stripboard prototype
    [TapuinoNext.fzz]
2021-08-26 fix? prototype build doc
2021-08-26 Update PrototypeBuild.md
    fixed PNGs display (damn upper case extension :( )
2021-09-02 Fixed pinout across all of the schematics, hopefully for the last time
    [TapuinoNext-Micro.brd, TapuinoNext-Micro.sch, TapuinoNext-Mini.brd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]
2021-09-17 - rewrote some of the options code seems to fix a heap corruption error - fixed a bug in the options menu handling copypasta on the wrong class type - updated the documentation the mini board has now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
    [LCD_HD44780.cpp, Options.cpp]
2021-09-20 added mini reference board image
2022-05-03 Fixed recording issue Cleaned up some code Starterd on some user documentation
    [LCDUtils.cpp, RecordSelector.cpp, TapRecorder.cpp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]
2022-05-05 Fixed Platformio version to 4.1.0 to avoid 4.2.0 broken timer behaviour
    [LCDUtils.cpp, TapBase.h, TapRecorder.cpp]
2022-06-04 Fixed various compatibility issues with framework-arduinoespressif32 > 2.0.1 - the platform is pinned to version 4.0.1 (and hence framework 2.0.1) waiting for timer fixes to get into the next framewo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
    Other minor improvments
    - changed the text for the firmware update menu to make it less confusing
    - added the spinner UI into the update prog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
    [ESP32InputHandler.cpp, ESP32TapLoader.cpp, LCDUtils.cpp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]
2022-06-10 Fixed version handling for actions and added auto change log (#3)
    * initial tapecart test
    * Minor changes to how version and releases work.
    * more version and release changes
    * missed build gate for release notes
    * more release note fixes
    * again
    * again again
    * test ls
    * woohoo! releasenotes work!
    * commenting tapecart stuff for main merge
    * minor readme changes
    [ESP32TapeCartLoader.cpp, TapBase.cpp]
2022-06-22 Tape cart impl (#4)
    * Moved buffer handling to FlipBuffer
    * Initial functional implementation of TapeCartLoader and other minor fixes
    * Cleanup of unused parameters
    * Minor cleanup of comments etc.
    * updated release notes
    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
    [ESP32TapLoader.cpp, ESP32TapeCartLoader.cpp]

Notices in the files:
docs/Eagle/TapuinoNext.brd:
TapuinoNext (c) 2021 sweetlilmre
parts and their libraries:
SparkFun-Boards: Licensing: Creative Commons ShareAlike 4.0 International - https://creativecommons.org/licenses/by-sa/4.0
